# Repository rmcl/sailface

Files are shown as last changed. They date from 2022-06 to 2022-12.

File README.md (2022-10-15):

# SailFace

An autonomous (non-sail powered) boat thing.

# Photos

## Mark II

## Mark I

# Code organization

## Microcontroller (sailface)

Runs on an arduino MEGA. This code manages navigation, communication and power management.

## Control (sailface_control)

Python code for controling sailface remotely.

### Lambda Data Capture (lambda_data_capture)

This module is a lambda function that will receive the messages relayed from the Iridium Short-Burst Data (SBD) network via the RockBLOCK service (https://docs.rockblock.rock7.com/docs/getting-started). 

### Command Lib (sailface_command)

A python library for creating command messages that can be sent to the vessel.

### Notebooks

Various jupyter notebooks for processing KML + sending commands to the vessel.

## Schematics

PCB/Schematic Designs for an Arduino shield which connects the various electronic components. Created using KiCAD

## 3dmodels

3d models for various parts largely for supporting the internals of the vessel.

# Communication

The Arduino communicates sends messages to the Iridium Short-Burst Data services via a RockBLOCK 9603.

SailFace status messages:

### Power

```
P:<batteryVoltage>,batteryCurrentDraw,solarPanelCurrent
P:3.70,500,400
```

### Navigation/Position

```
N:<positionValid>,<latitude>,<longitude>,<speed>,<course>,<gpsFixAge>
```

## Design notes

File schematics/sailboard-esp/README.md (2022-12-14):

Changelog
##################

Version 1.1
---------------------
* Moved towards using a buck converter from Vin to 5V and then a simple linear regulator for 5v to 3.3v

Version 1.2
------------------
* Added dampening capacitor next to servo.

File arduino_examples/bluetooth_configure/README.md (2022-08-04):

# Bluetooth Configure

These sketches can be used to enter AT mode of the HC-05 bluetooth module. The Arduino forwards serial commands enter from a connect computer to the bluetooth module. The serial connection to the module is opened at baud rate 38400 which causes the device to enter AT command mode.

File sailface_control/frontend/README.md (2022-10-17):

# to test in a browser run:

```
python3 -m http.server
```

Then navigate to localhost:8000/examples.html

# Useful links

* https://map.openseamap.org/
* https://wiki.openseamap.org/wiki/h:De:OpenSeaMap_in_Website
* https://mcuoneclipse.com/2014/06/07/combining-gps-data-logger-with-google-earth/
* https://simplekml.readthedocs.io/en/latest/gettingstarted.html#creating-a-point
* https://blog.nicolasmesa.co/posts/2018/09/serve-your-current-directory-with-python-and-http/
* https://wiki.openseamap.org/wiki/h:De:OpenSeaMap_in_Website
* https://mcuoneclipse.com/2014/06/07/combining-gps-data-logger-with-google-earth/
* https://simplekml.readthedocs.io/en/latest/gettingstarted.html#creating-a-point
* https://blog.nicolasmesa.co/posts/2018/09/serve-your-current-directory-with-python-and-http/

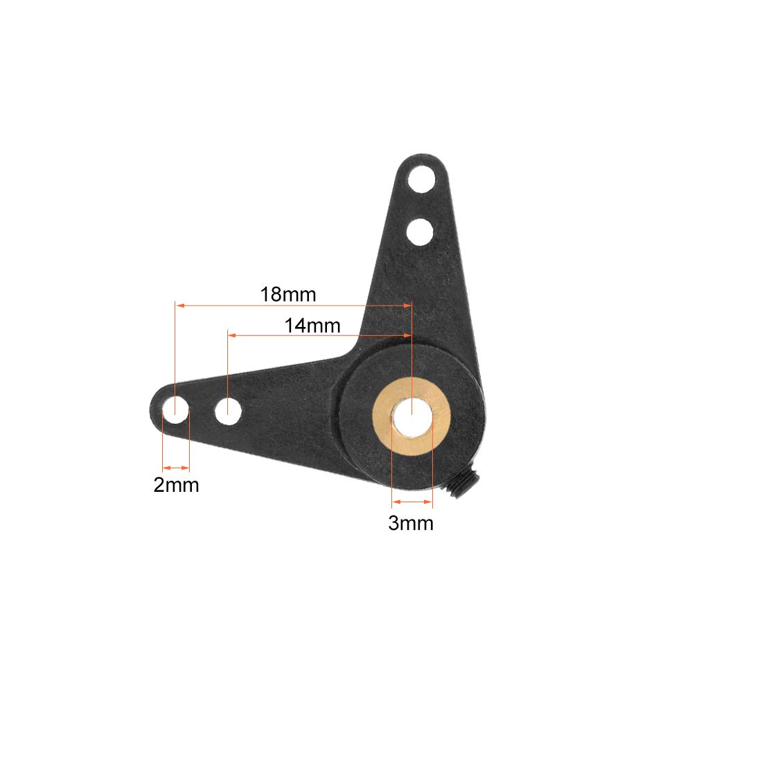
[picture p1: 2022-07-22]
3dmodels/part-photos/rudder_connector.png

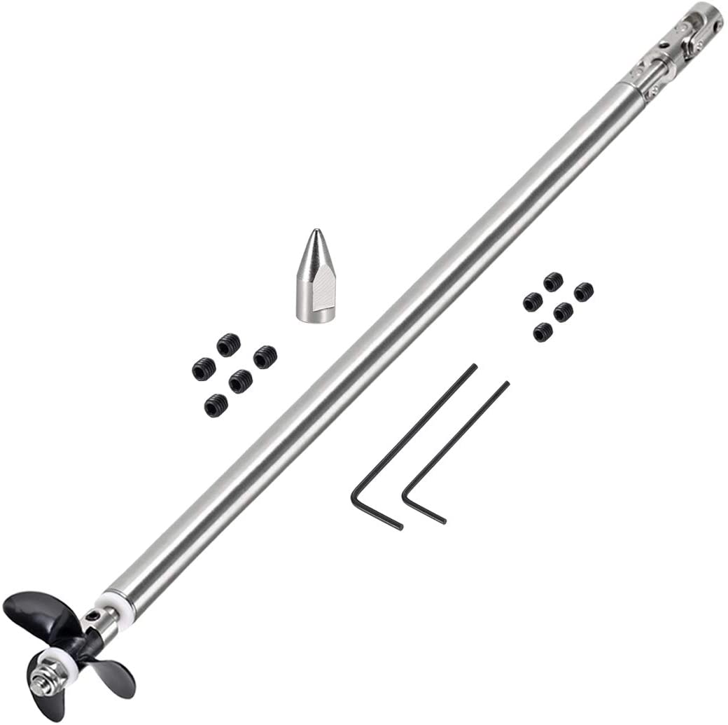
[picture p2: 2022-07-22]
3dmodels/part-photos/prop_with_sleeve.jpeg

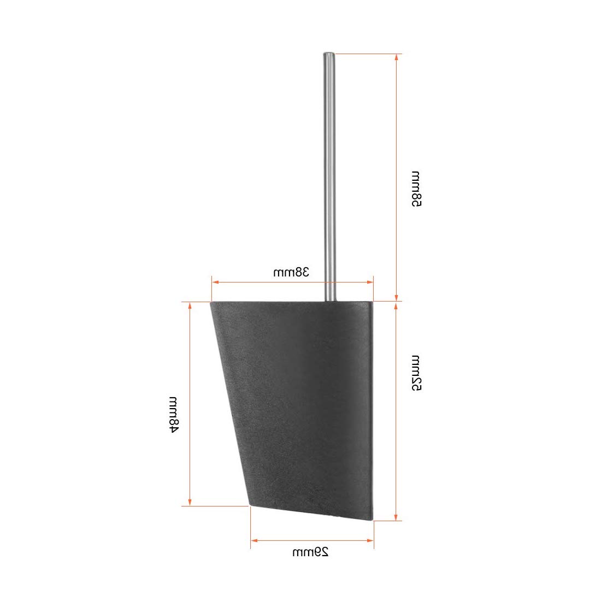
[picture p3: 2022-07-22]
3dmodels/part-photos/rudder.jpg

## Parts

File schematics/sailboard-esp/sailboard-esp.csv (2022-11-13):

Source: | /Users/rmcl/Documents/Arduino/sailface/schematics/sailboard/sailboard.kicad_sch
Date: | Tuesday, September 27, 2022 at 10:22:36 PM
Tool: | Eeschema (6.0.6-0)
Generator: | /Applications/KiCad/KiCad.app/Contents/SharedSupport/plugins/bom_csv_grouped_by_value.py
Component Count: | 29
Individual Components:
Item | Qty | Reference(s) | Value | LibPart | Footprint | Datasheet
 |  | ArduCam1 | ArduCamShield_OV2640 | Russell:ArduCamShield_OV2640 | Connector_PinHeader_2.00mm:PinHeader_1x08_P2.00mm_Vertical
 |  | ATMEGA1 | ATmega2560-16A | Russell:ATmega2560-16A-CustomPins | Package_QFP:TQFP-100_14x14mm_P0.5mm | http://ww1.microchip.com/downloads/en/DeviceDoc/Atmel-2549-8-bit-AVR-Microcontroller-ATmega640-1280-1281-2560-2561_datasheet.pdf
 |  | BATIN1 | BatteryInput | Connector:Conn_01x02_Male | Connector_PinHeader_2.00mm:PinHeader_1x02_P2.00mm_Vertical | ~
 |  | C1 | C | Device:C | Capacitor_SMD:C_0603_1608Metric | ~
 |  | C2 | .1uF | Device:C | Capacitor_SMD:C_0603_1608Metric | ~
 |  | C3 | C | Device:C | Capacitor_SMD:C_0603_1608Metric | ~
 |  | C4 | 10uF | Device:C | Capacitor_SMD:C_0603_1608Metric | ~
 |  | C5 | 100n | Device:C | Capacitor_SMD:C_0603_1608Metric | ~
 |  | C6 | 100nF | Device:C | Capacitor_SMD:C_0603_1608Metric | ~
 |  | C7 | 22pF | Device:C | Capacitor_SMD:C_0603_1608Metric | ~
 |  | C8 | 22pF | Device:C | Capacitor_SMD:C_0603_1608Metric | ~
 |  | C9 | 100nF | Device:C | Capacitor_SMD:C_0603_1608Metric | ~
 |  | C10 | 100nF | Device:C | Capacitor_SMD:C_0603_1608Metric | ~
 |  | C11 | 100nF | Device:C | Capacitor_SMD:C_0603_1608Metric | ~
 |  | COMPASS1 | QMC5883L | Russell:QMC5883L | Connector_PinHeader_2.00mm:PinHeader_1x05_P2.00mm_Vertical | http://wiki.sunfounder.cc/index.php?title=QMC5883L
 |  | D1 | D_Schottky | Device:D_Schottky | Diode_THT:D_5W_P5.08mm_Vertical_AnodeUp | ~
 |  | D2 | LED | Device:LED | LED_SMD:LED_0402_1005Metric | ~
 |  | GPS1 | GPS | Russell:GPS | Connector_PinHeader_1.00mm:PinHeader_1x04_P1.00mm_Vertical
 |  | IRIDIUM1 | IRIDIUM | Russell:IRIDIUM | Connector_PinHeader_2.00mm:PinHeader_1x10_P2.00mm_Vertical | ~
 |  | ISP1 | AVR-ISP-6 | Connector:AVR-ISP-6 | Connector_PinHeader_2.54mm:PinHeader_2x03_P2.54mm_Vertical | ~
 |  | J2 | MainPowerSwitch | Connector:Conn_01x02_Male | Connector_PinHeader_2.00mm:PinHeader_1x02_P2.00mm_Vertical | ~
 |  | MOTOR1 | MOTOR | Connector_Generic:Conn_01x02 | Connector_PinHeader_2.00mm:PinHeader_1x02_P2.00mm_Vertical | ~
 |  | R1 | 1K | Device:R_US | Resistor_SMD:R_0603_1608Metric | ~
 |  | RUDDER1 | RUDDERSERVO | Connector_Generic:Conn_01x03 | Connector_PinHeader_2.00mm:PinHeader_1x03_P2.00mm_Vertical | ~
 |  | SDCARD1 | SD Card | Russell:SD Card | Connector_PinHeader_2.00mm:PinHeader_1x06_P2.00mm_Vertical | https://www.amazon.com/dp/B07BJ2P6X6?psc=1&ref=ppx_yo2ov_dt_b_product_details
 |  | U1 | uA7805 | Regulator_Linear:uA7805 | Package_TO_SOT_THT:TO-220-3_Vertical | http://www.ti.com/lit/ds/symlink/ua78.pdf
 |  | U2 | LM2937xMP | Regulator_Linear:LM2937xMP | Package_TO_SOT_SMD:SOT-223-3_TabPin2 | http://www.ti.com/lit/ds/symlink/lm2937.pdf
 |  | U3 | L293D | Driver_Motor:L293D | Package_DIP:DIP-16_W7.62mm | http://www.ti.com/lit/ds/symlink/l293.pdf
 |  | Y1 | 16MHZ | Device:Crystal | Crystal:Crystal_HC49-4H_Vertical | ~
Collated Components:
Item | Qty | Reference(s) | Value | LibPart | Footprint | Datasheet
1 | 1 | ArduCam1 | ArduCamShield_OV2640 | Russell:ArduCamShield_OV2640 | Connector_PinHeader_2.00mm:PinHeader_1x08_P2.00mm_Vertical
2 | 1 | ATMEGA1 | ATmega2560-16A | Russell:ATmega2560-16A-CustomPins | Package_QFP:TQFP-100_14x14mm_P0.5mm | http://ww1.microchip.com/downloads/en/DeviceDoc/Atmel-2549-8-bit-AVR-Microcontroller-ATmega640-1280-1281-2560-2561_datasheet.pdf
3 | 1 | BATIN1 | BatteryInput | Connector:Conn_01x02_Male | Connector_PinHeader_2.00mm:PinHeader_1x02_P2.00mm_Vertical | ~
4 | 2 | C1, C3 | C | Device:C | Capacitor_SMD:C_0603_1608Metric | ~
5 | 1 | C2 | .1uF | Device:C | Capacitor_SMD:C_0603_1608Metric | ~
6 | 1 | C4 | 10uF | Device:C | Capacitor_SMD:C_0603_1608Metric | ~
7 | 1 | C5 | 100n | Device:C | Capacitor_SMD:C_0603_1608Metric | ~
8 | 4 | C6, C9, C10, C11 | 100nF | Device:C | Capacitor_SMD:C_0603_1608Metric | ~
9 | 2 | C7, C8 | 22pF | Device:C | Capacitor_SMD:C_0603_1608Metric | ~
10 | 1 | COMPASS1 | QMC5883L | Russell:QMC5883L | Connector_PinHeader_2.00mm:PinHeader_1x05_P2.00mm_Vertical | http://wiki.sunfounder.cc/index.php?title=QMC5883L
11 | 1 | D1 | D_Schottky | Device:D_Schottky | Diode_THT:D_5W_P5.08mm_Vertical_AnodeUp | ~
12 | 1 | D2 | LED | Device:LED | LED_SMD:LED_0402_1005Metric | ~
13 | 1 | GPS1 | GPS | Russell:GPS | Connector_PinHeader_1.00mm:PinHeader_1x04_P1.00mm_Vertical
14 | 1 | IRIDIUM1 | IRIDIUM | Russell:IRIDIUM | Connector_PinHeader_2.00mm:PinHeader_1x10_P2.00mm_Vertical | ~
15 | 1 | ISP1 | AVR-ISP-6 | Connector:AVR-ISP-6 | Connector_PinHeader_2.54mm:PinHeader_2x03_P2.54mm_Vertical | ~
16 | 1 | J2 | MainPowerSwitch | Connector:Conn_01x02_Male | Connector_PinHeader_2.00mm:PinHeader_1x02_P2.00mm_Vertical | ~
17 | 1 | MOTOR1 | MOTOR | Connector_Generic:Conn_01x02 | Connector_PinHeader_2.00mm:PinHeader_1x02_P2.00mm_Vertical | ~
18 | 1 | R1 | 1K | Device:R_US | Resistor_SMD:R_0603_1608Metric | ~
19 | 1 | RUDDER1 | RUDDERSERVO | Connector_Generic:Conn_01x03 | Connector_PinHeader_2.00mm:PinHeader_1x03_P2.00mm_Vertical | ~
20 | 1 | SDCARD1 | SD Card | Russell:SD Card | Connector_PinHeader_2.00mm:PinHeader_1x06_P2.00mm_Vertical | https://www.amazon.com/dp/B07BJ2P6X6?psc=1&ref=ppx_yo2ov_dt_b_product_details
21 | 1 | U1 | uA7805 | Regulator_Linear:uA7805 | Package_TO_SOT_THT:TO-220-3_Vertical | http://www.ti.com/lit/ds/symlink/ua78.pdf
22 | 1 | U2 | LM2937xMP | Regulator_Linear:LM2937xMP | Package_TO_SOT_SMD:SOT-223-3_TabPin2 | http://www.ti.com/lit/ds/symlink/lm2937.pdf
23 | 1 | U3 | L293D | Driver_Motor:L293D | Package_DIP:DIP-16_W7.62mm | http://www.ti.com/lit/ds/symlink/l293.pdf
24 | 1 | Y1 | 16MHZ | Device:Crystal | Crystal:Crystal_HC49-4H_Vertical | ~

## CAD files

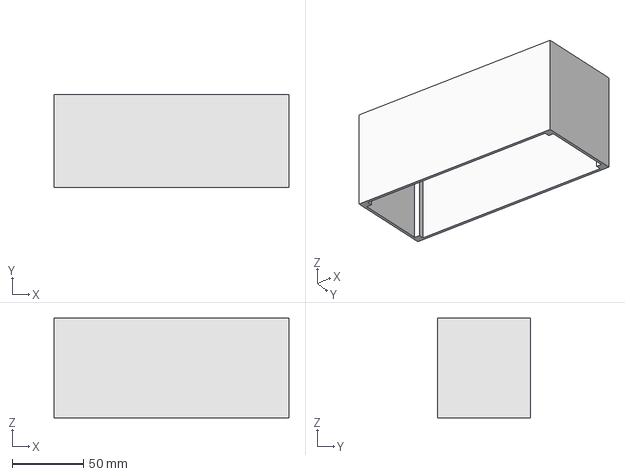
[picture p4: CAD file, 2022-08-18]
ElectronicAssembly_v2.1.FCStd
165.0 x 65.0 x 70.0 mm

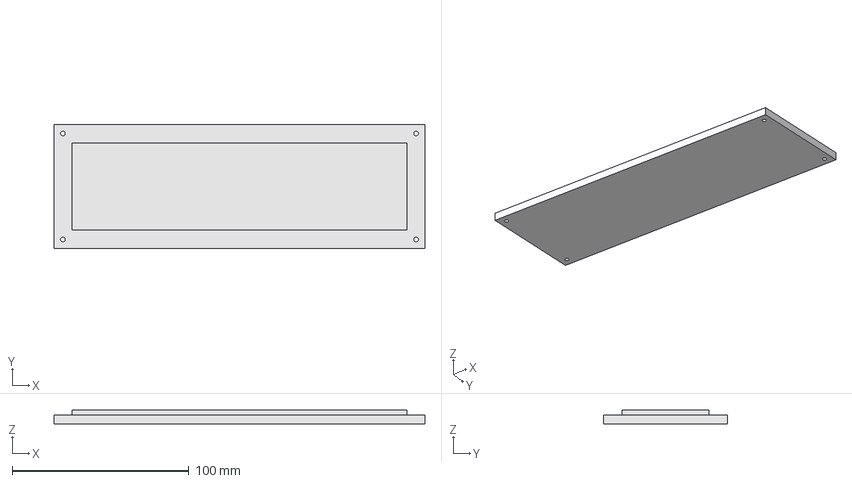
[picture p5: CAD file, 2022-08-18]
3dmodels/ElectronicAssembly_v3.FCStd
210.0 x 70.0 x 8.00 mm

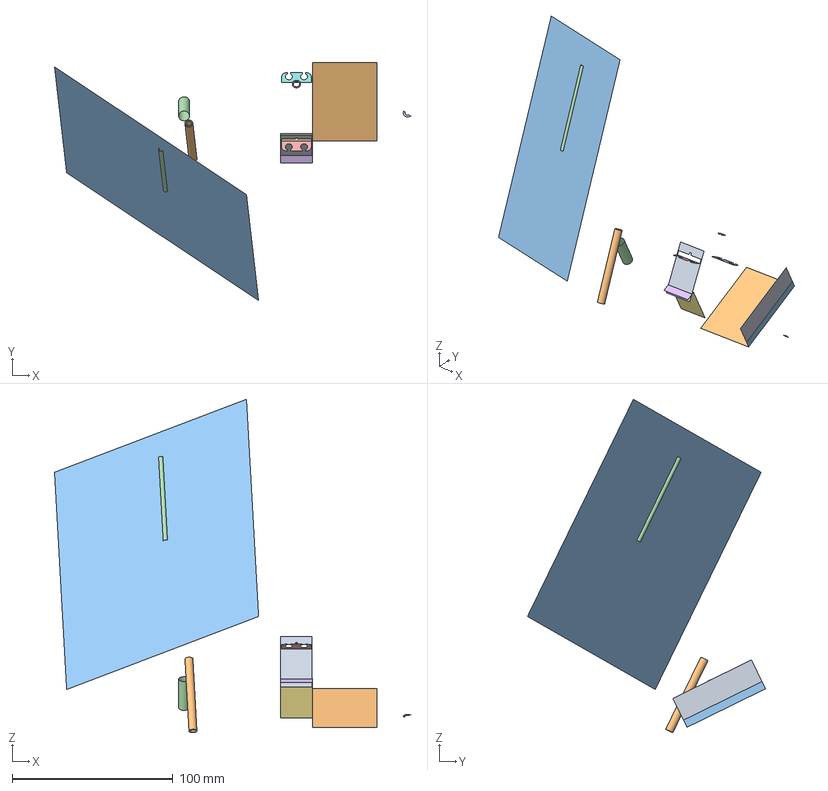
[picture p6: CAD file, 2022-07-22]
3dmodels/sailface_steerage_assembly_v1.FCStd
221.7 x 148.3 x 207.7 mm
Element
Element001
Element002
_Element
_Element002
_Element003
_Element004
_Element005
_Element008
_Element022
YZ_Plane@PartRudderWithPost
_Element025
_Element026
_Element027
_Element028

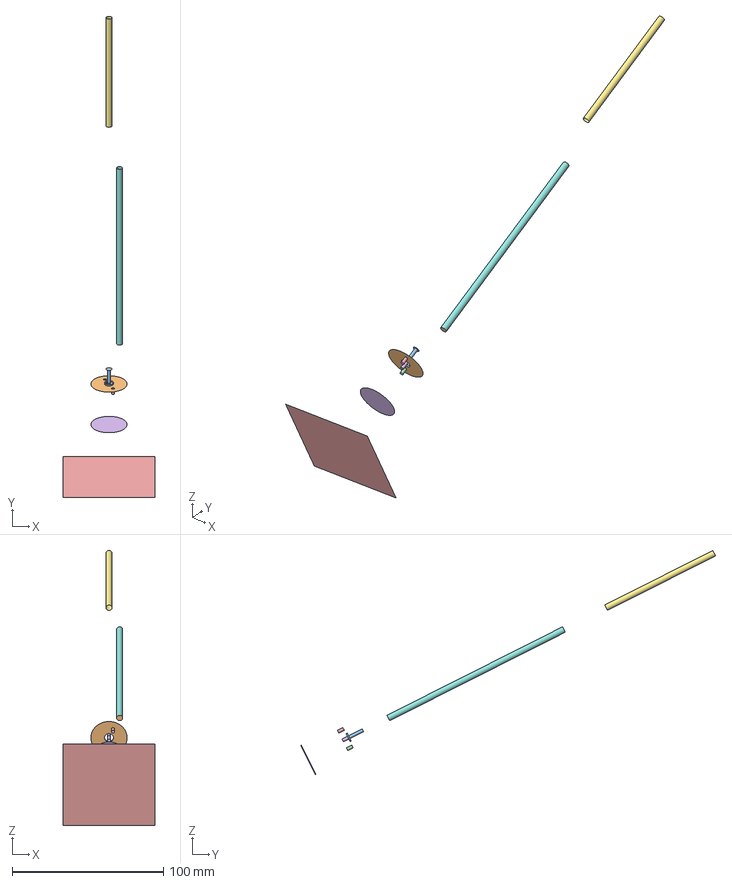
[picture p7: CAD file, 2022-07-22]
3dmodels/sailface_prop_motor_assembly.FCStd
60.5 x 317.8 x 181.6 mm
Element
Element001
Element002
Element003
Element004
_Element
_Element043
_Element044
_Element045
_Element046
_Element047
_Element048
_Element049
_Element050

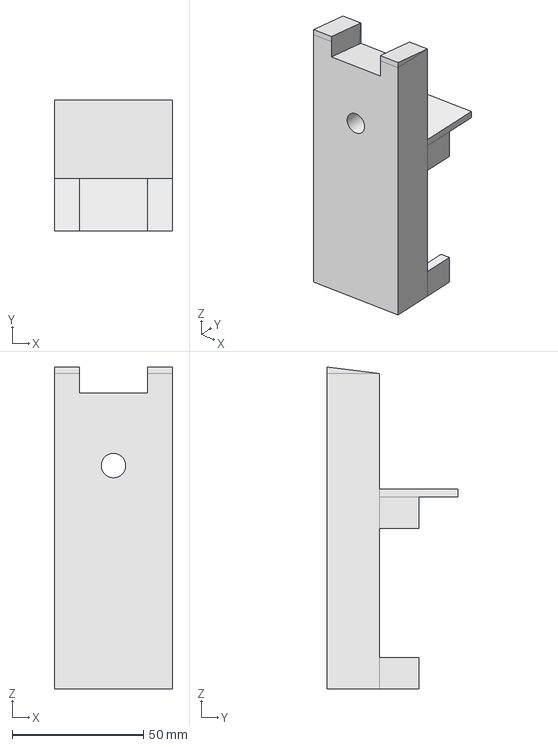
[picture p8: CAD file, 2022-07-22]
3dmodels/sailface_vertical_assembly_v3.FCStd
45.0 x 50.0 x 122.5 mm

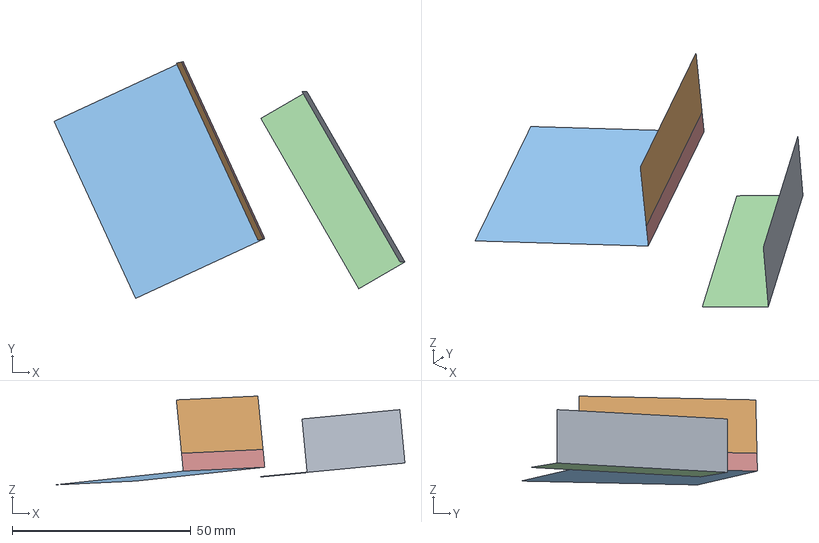
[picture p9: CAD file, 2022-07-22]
3dmodels/sailface_assembly_v2.FCStd
98.1 x 66.2 x 24.9 mm
_Element
_Element001
_Element002
_Element003
_Element004

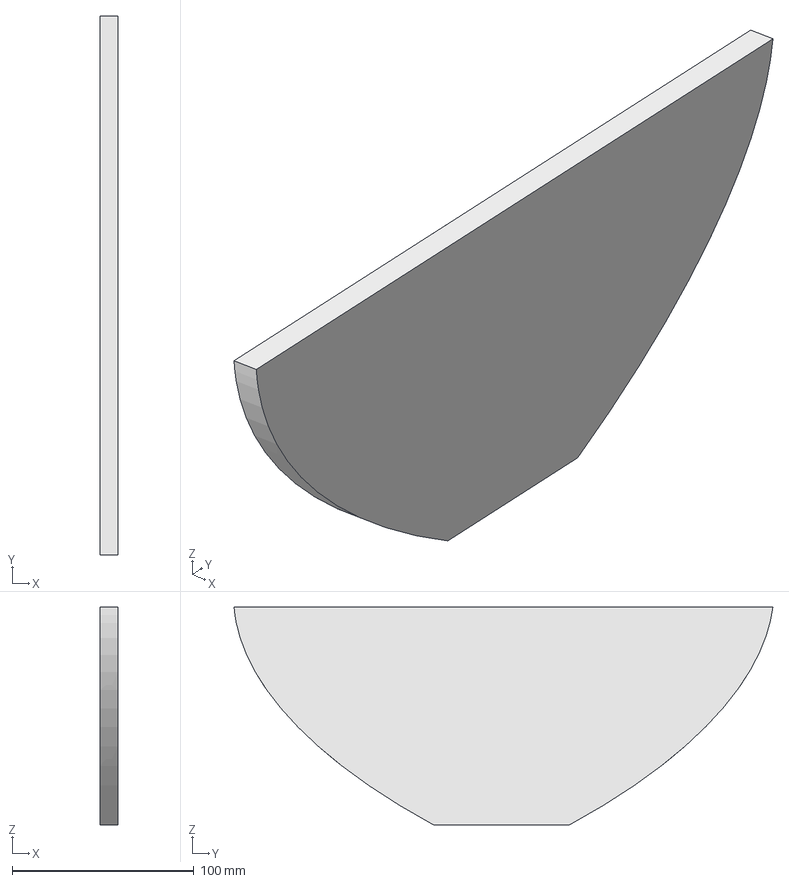
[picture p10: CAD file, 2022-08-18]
3dmodels/hull-experiments/hull_v3.FCStd
10.0 x 296.7 x 120.0 mm

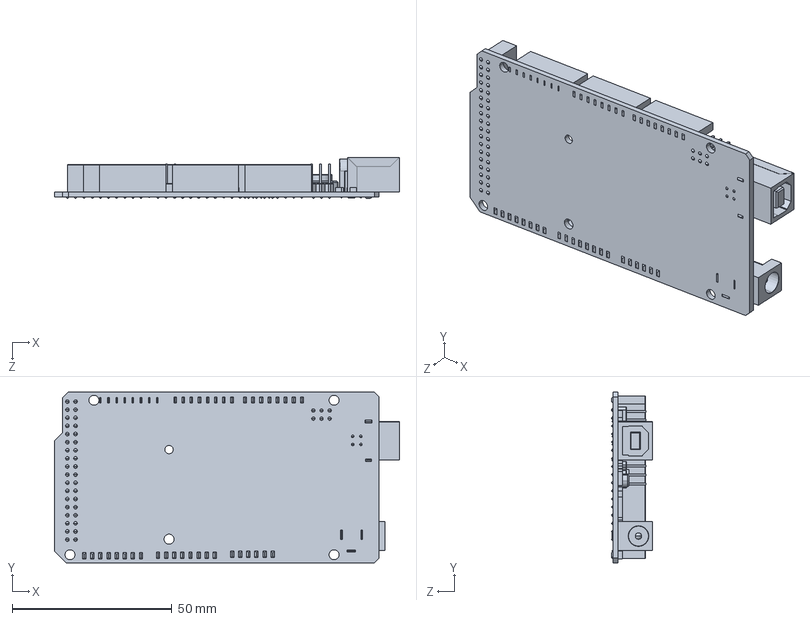
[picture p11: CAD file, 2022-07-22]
3dmodels/part-photos/ArduinoMega_STEP_AP203.STEP
107.9 x 53.4 x 13.0 mm

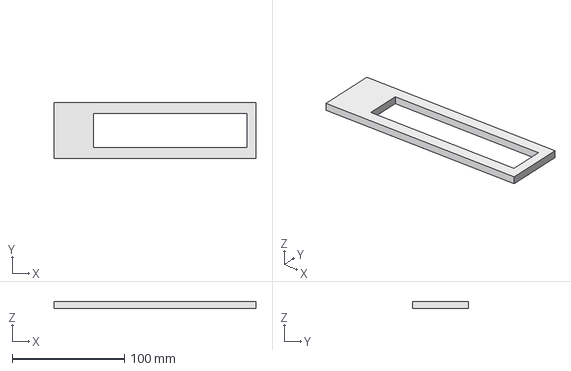
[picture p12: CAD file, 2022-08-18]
3dmodels/MiddleConnector_v1.FCStd
180.0 x 50.0 x 6.00 mm

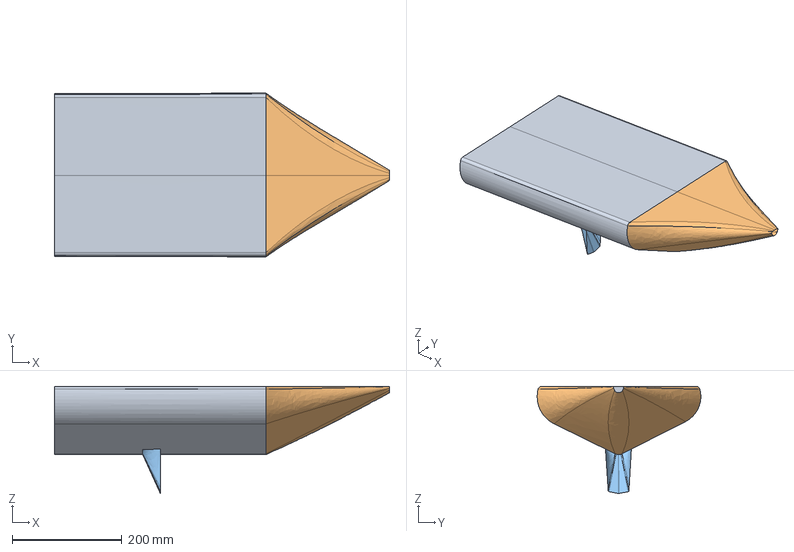
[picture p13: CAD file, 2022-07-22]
3dmodels/hull-experiments/hulltest6.FCStd
610.0 x 298.0 x 195.0 mm

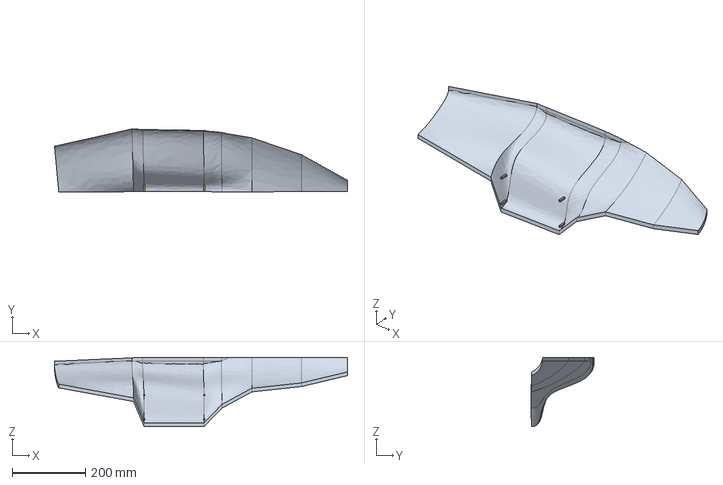
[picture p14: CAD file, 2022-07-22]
3dmodels/hull-experiments/hulltest9_BACKUP.FCStd
801.2 x 173.3 x 190.0 mm
ExtrudeBatteryHolder

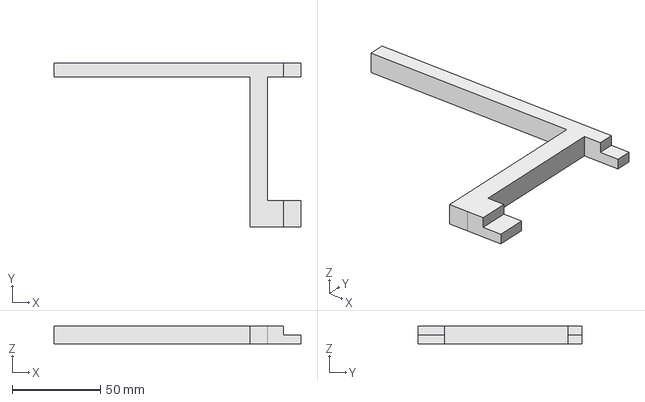
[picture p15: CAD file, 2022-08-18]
3dmodels/SolarPanelSupports_v2.FCStd
140.0 x 93.0 x 10.0 mm

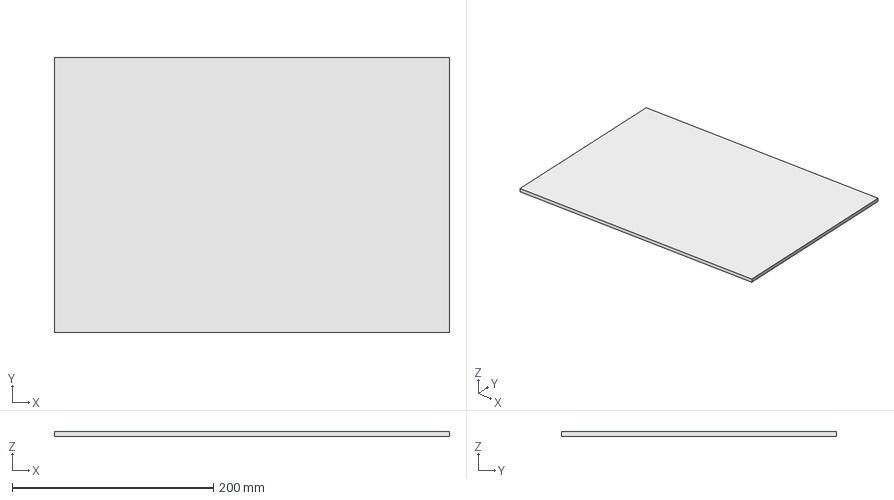
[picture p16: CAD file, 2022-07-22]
3dmodels/sailface.FCStd
393.0 x 274.0 x 5.00 mm

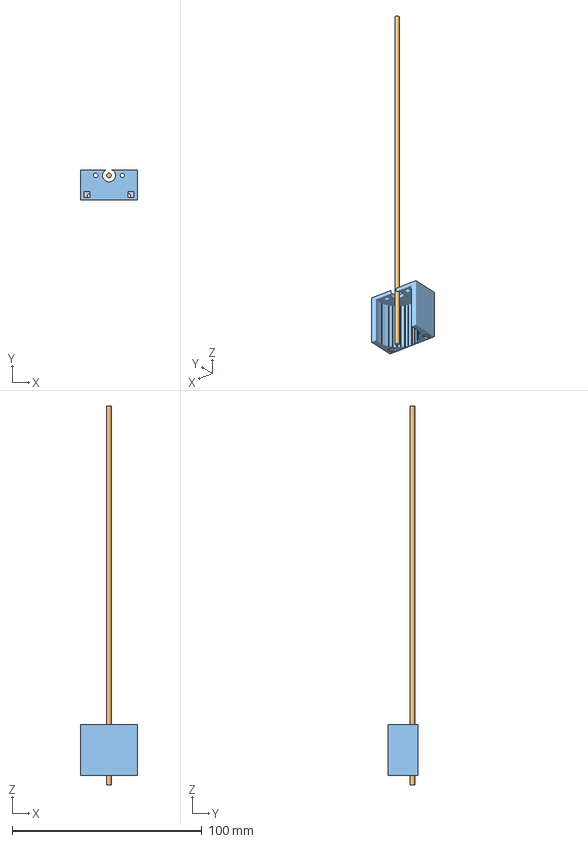
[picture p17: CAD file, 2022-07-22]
3dmodels/motor.FCStd
30.0 x 16.0 x 200.0 mm
MotorHolderBody
MotorHolder (Meshed)

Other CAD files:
3dmodels/assembly4test.FCStd
3dmodels/hull-experiments/hulltest2.FCStd
3dmodels/hull-experiments/hulltest4.FCStd
3dmodels/hull-experiments/hulltest9.FCStd
3dmodels/Battery_VoltaicV70.FCStd
3dmodels/ElectronicAssembly.FCStd
3dmodels/ElectronicAssembly_v2.FCStd
3dmodels/GPSAntennaHolder_v1.FCStd
3dmodels/MotorAndHolder_v1.FCStd
3dmodels/MotorHolderConnect_v1.FCStd
3dmodels/Prop_uxcell_prop_shaft.FCStd
3dmodels/ServoHolder_v2.FCStd
3dmodels/ServoHolder_v3.FCStd
3dmodels/ServoSunFinderSF3218MG.FCStd
3dmodels/ServoSunFinderSF3218MG_v2.FCStd
3dmodels/SolarPanelSupports_v1.FCStd
3dmodels/hull-experiments/hull_v1.FCStd
3dmodels/hull-experiments/hull_v2.FCStd
3dmodels/hull-experiments/hullexperiment-1.FCStd
3dmodels/hull-experiments/hulltest3.FCStd
3dmodels/hull-experiments/hulltest5.FCStd
3dmodels/hull-experiments/hulltest7.FCStd
3dmodels/hull-experiments/hulltest8.FCStd
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

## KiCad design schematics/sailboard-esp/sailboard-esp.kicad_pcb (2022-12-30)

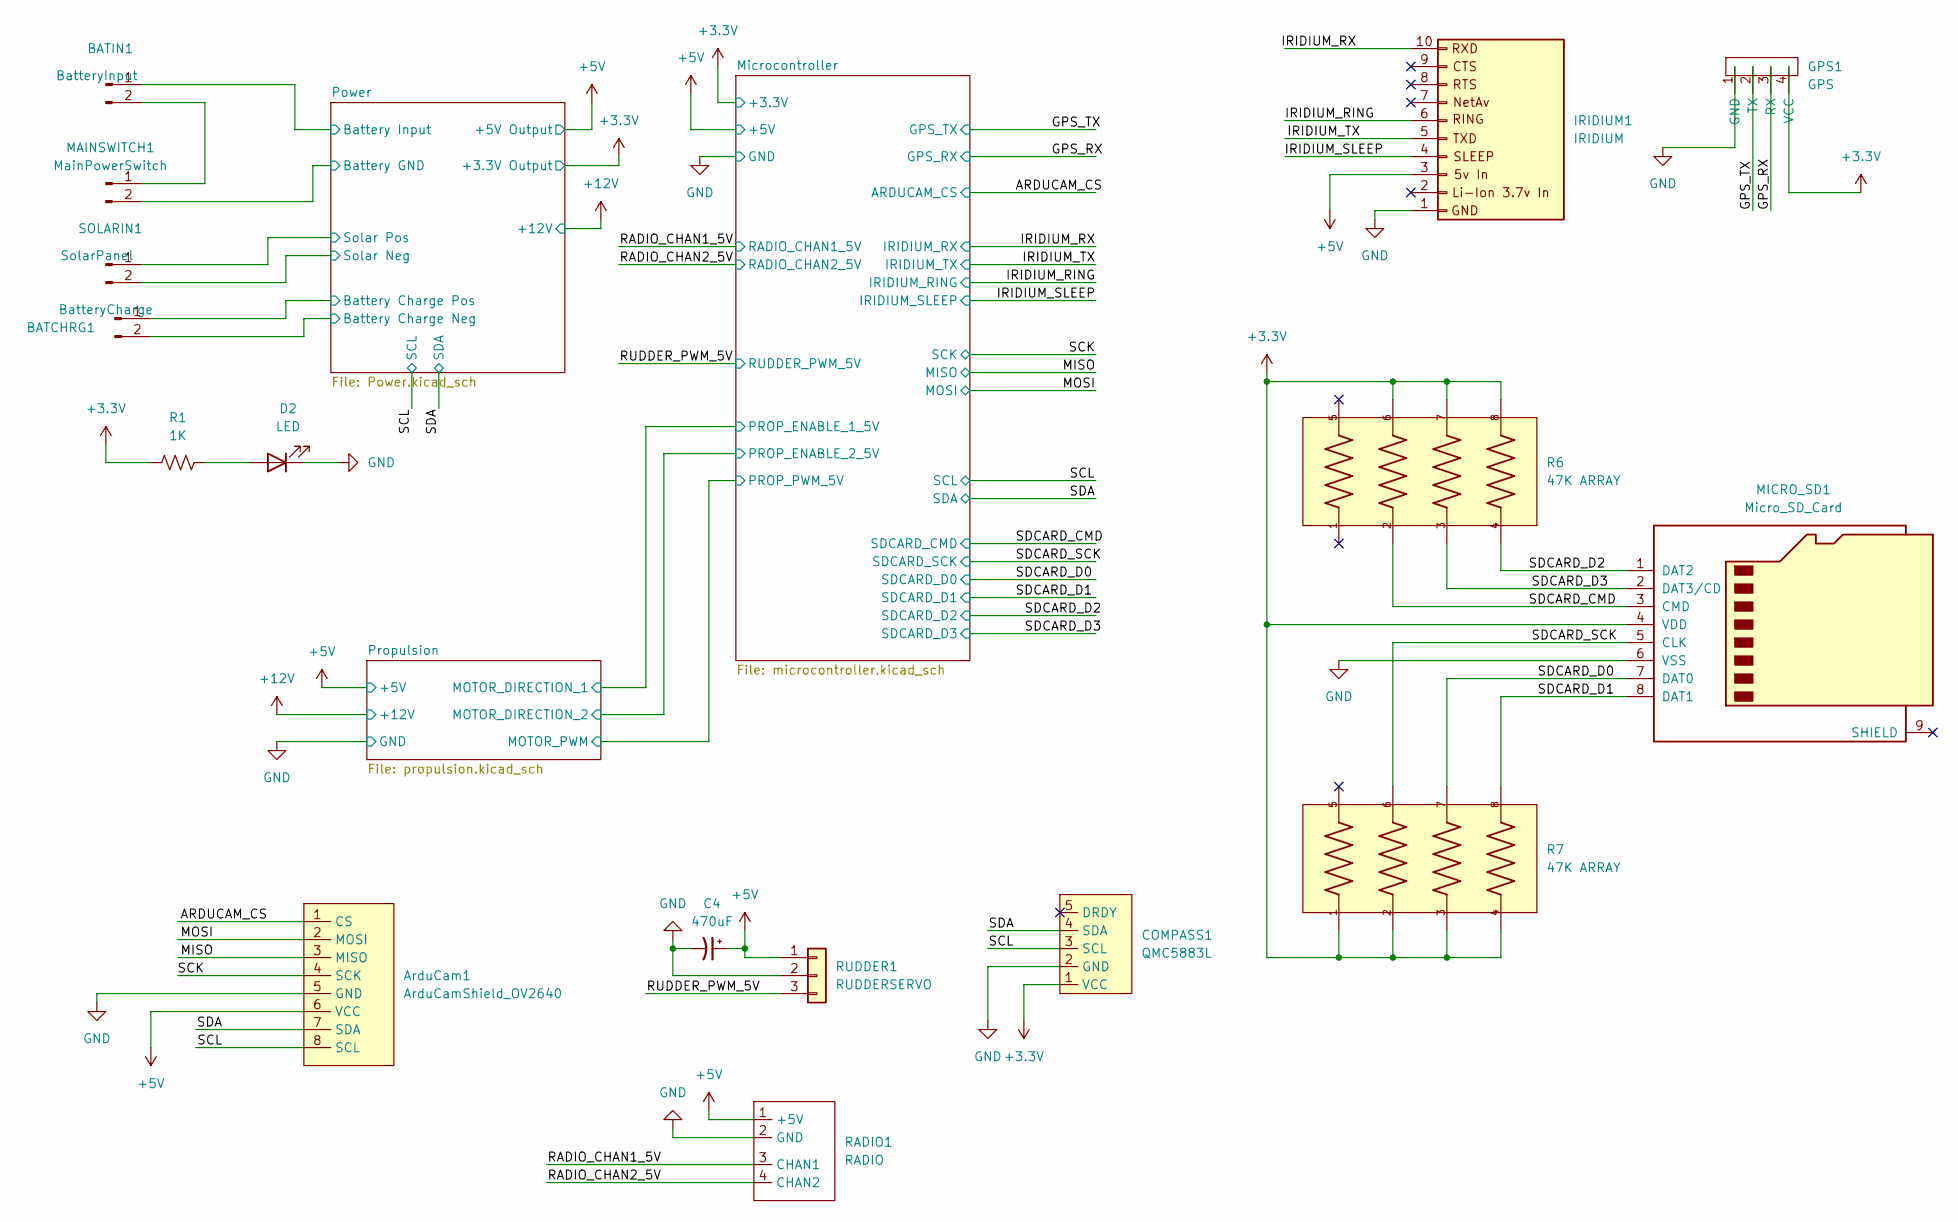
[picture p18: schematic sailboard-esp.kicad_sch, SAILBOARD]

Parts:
ArduCam1: ArduCamShield_OV2640; PinHeader_1x08_P2.54mm_Vertical
BATCHRG1: BatteryCharge; JST_XH_B2B-XH-A_1x02_P2.50mm_Vertical
BATIN1: BatteryInput; JST_XH_B2B-XH-A_1x02_P2.50mm_Vertical
C4: 470uF; CP_Radial_D8.0mm_P3.50mm
COMPASS1: QMC5883L; PinHeader_1x05_P2.54mm_Vertical
D2: LED; LED_0603_1608Metric
GPS1: GPS; PinHeader_1x04_P2.54mm_Vertical
IRIDIUM1: IRIDIUM; Molex_PicoBlade_53047-1010_1x10_P1.25mm_Vertical
MAINSWITCH1: MainPowerSwitch; JST_XH_B2B-XH-A_1x02_P2.50mm_Vertical
MICRO_SD1: Micro_SD_Card; microSD_HC_Molex_104031-0811
R1: 1K; R_0603_1608Metric
R6, R7: 47K ARRAY; RESCAXE80P320X160X70-8N; PARTREV 0
RADIO1: RADIO; PinHeader_1x04_P2.54mm_Vertical
RUDDER1: RUDDERSERVO; JST_XH_B3B-XH-A_1x03_P2.50mm_Vertical
SOLARIN1: SolarPanel; JST_XH_B2B-XH-A_1x02_P2.50mm_Vertical

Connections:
+3.3V: COMPASS1.1 (VCC), GPS1.4 (VCC), MICRO_SD1.4 (VDD), R1.1, R6.6, R6.7, R6.8, R7.1, R7.2, R7.3, R7.4; also elsewhere on the board
+5V: ArduCam1.6 (VCC), C4.1, IRIDIUM1.3 (5V), RADIO1.1 (+5V), RUDDER1.1; also elsewhere on the board
/ARDUCAM_CS: ArduCam1.1 (CS); also elsewhere on the board
/GPS_RX: GPS1.3 (RX)
/GPS_TX: GPS1.2 (TX); also elsewhere on the board
/IRIDIUM_RING: IRIDIUM1.6 (RING); also elsewhere on the board
/IRIDIUM_RX: IRIDIUM1.10 (RXD); also elsewhere on the board
/IRIDIUM_SLEEP: IRIDIUM1.4 (SLEEP); also elsewhere on the board
/IRIDIUM_TX: IRIDIUM1.5 (TXD); also elsewhere on the board
/MISO: ArduCam1.3 (MISO); also elsewhere on the board
/MOSI: ArduCam1.2 (MOSI); also elsewhere on the board
/Power/Battery Charge Neg: BATCHRG1.2, SOLARIN1.2
/Power/Battery Charge Pos: BATCHRG1.1; also elsewhere on the board
/Power/Battery Input: BATIN1.1; also elsewhere on the board
/Power/Solar Pos: SOLARIN1.1; also elsewhere on the board
/RADIO_CHAN1_5V: RADIO1.3 (CHAN1); also elsewhere on the board
/RADIO_CHAN2_5V: RADIO1.4 (CHAN2); also elsewhere on the board
/RUDDER_PWM_5V: RUDDER1.3; also elsewhere on the board
/SCK: ArduCam1.4 (SCK); also elsewhere on the board
/SCL: ArduCam1.8 (SCL), COMPASS1.3 (SCL); also elsewhere on the board
/SDA: ArduCam1.7 (SDA), COMPASS1.4 (SDA); also elsewhere on the board
/SDCARD_CMD: MICRO_SD1.3 (CMD), R6.2; also elsewhere on the board
/SDCARD_D0: MICRO_SD1.7 (DAT0), R7.7; also elsewhere on the board
/SDCARD_D1: MICRO_SD1.8 (DAT1), R7.8; also elsewhere on the board
/SDCARD_D2: MICRO_SD1.1 (DAT2), R6.4; also elsewhere on the board
/SDCARD_D3: MICRO_SD1.2 (DAT3/CD), R6.3; also elsewhere on the board
/SDCARD_SCK: MICRO_SD1.5 (CLK), R7.6; also elsewhere on the board
GND: ArduCam1.5 (GND), C4.2, COMPASS1.2 (GND), D2.1 (K), GPS1.1 (GND), IRIDIUM1.1 (GND), MAINSWITCH1.2, MICRO_SD1.6 (VSS), RADIO1.2 (GND), RUDDER1.2; also elsewhere on the board
unnamed: BATIN1.2, MAINSWITCH1.1
unnamed: D2.2 (A), R1.2

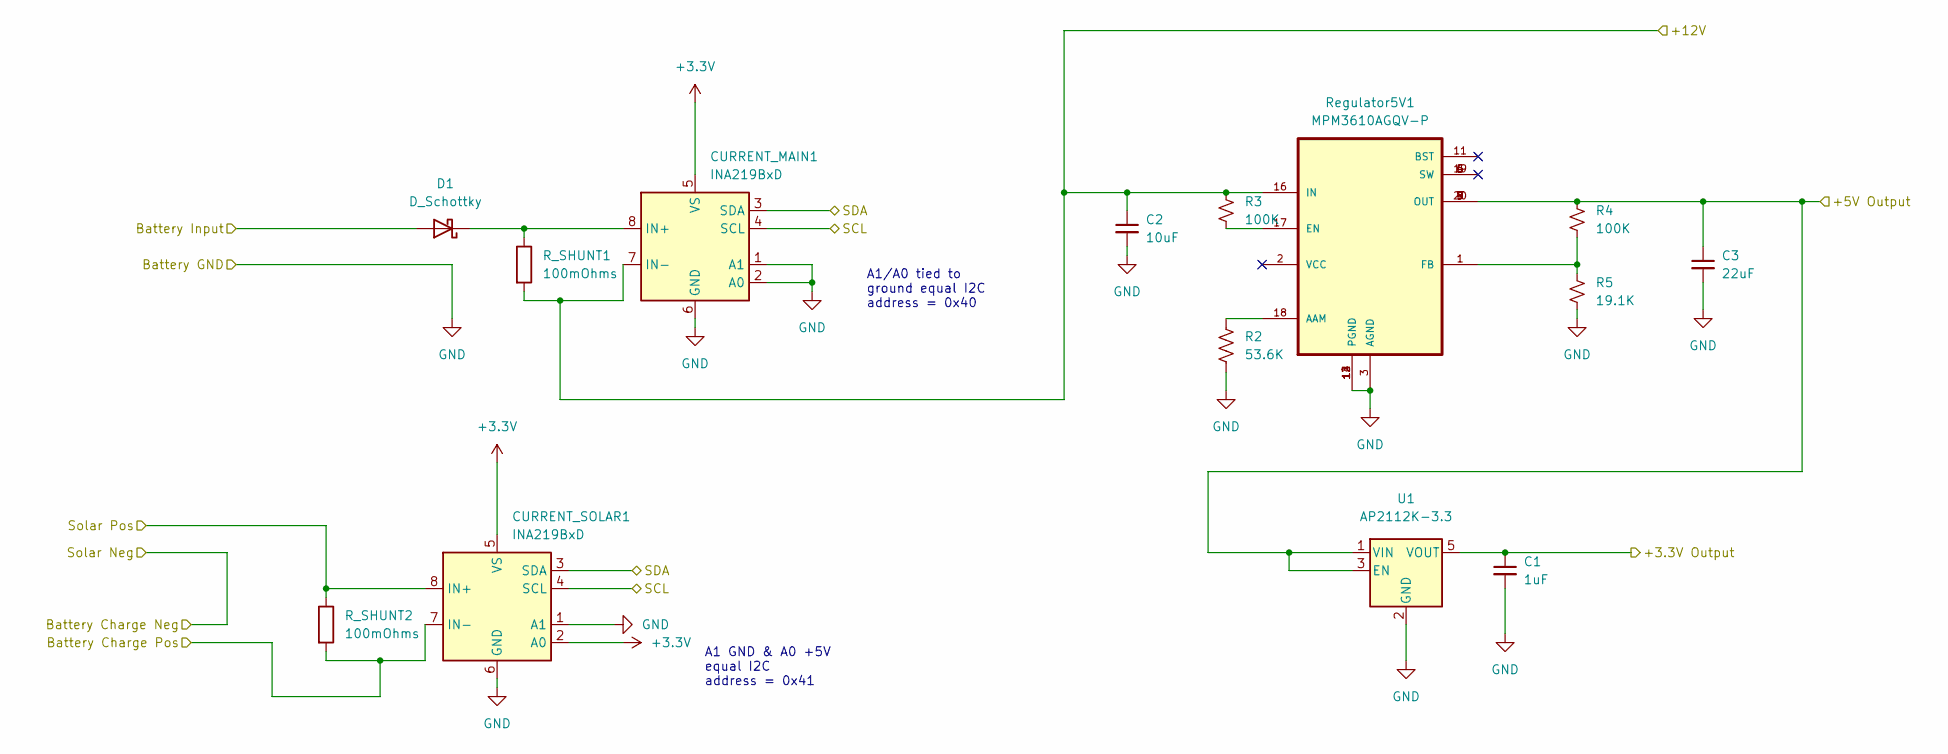
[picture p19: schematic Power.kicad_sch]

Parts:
C1: 1uF; C_0603_1608Metric_Pad1.08x0.95mm_HandSolder
C2: 10uF; C_0603_1608Metric_Pad1.08x0.95mm_HandSolder
C3: 22uF; C_0603_1608Metric_Pad1.08x0.95mm_HandSolder
CURRENT_MAIN1: INA219BxD; SOIC-8_3.9x4.9mm_P1.27mm
CURRENT_SOLAR1: INA219BxD; SOIC-8_3.9x4.9mm_P1.27mm
D1: D_Schottky; D_5W_P5.08mm_Vertical_AnodeUp
R2: 53.6K; R_0603_1608Metric
R3, R4: 100K; R_0603_1608Metric
R5: 19.1K; R_0603_1608Metric
R_SHUNT1, R_SHUNT2: 100mOhms; R_2512_6332Metric
Regulator5V1: MPM3610AGQV-P; MPM3620AGQV-P; PARTREV 1.0
U1: AP2112K-3.3; SOT-23-5

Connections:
+3.3V: C1.1, CURRENT_MAIN1.5 (VS), CURRENT_SOLAR1.2 (A0), CURRENT_SOLAR1.5 (VS), U1.5 (VOUT); also elsewhere on the board
+5V: C3.1, R4.1, Regulator5V1.7 (OUT), Regulator5V1.8 (OUT), Regulator5V1.9 (OUT), Regulator5V1.20 (OUT), U1.1 (VIN), U1.3 (EN); also elsewhere on the board
+12V: C2.1, CURRENT_MAIN1.7 (IN-), R3.1, R_SHUNT1.2, Regulator5V1.16 (IN); also elsewhere on the board
/Power/Battery Charge Pos: CURRENT_SOLAR1.7 (IN-), R_SHUNT2.2; also elsewhere on the board
/Power/Battery Input: D1.2 (A); also elsewhere on the board
/Power/Solar Pos: CURRENT_SOLAR1.8 (IN+), R_SHUNT2.1; also elsewhere on the board
/SCL: CURRENT_MAIN1.4 (SCL), CURRENT_SOLAR1.4 (SCL); also elsewhere on the board
/SDA: CURRENT_MAIN1.3 (SDA), CURRENT_SOLAR1.3 (SDA); also elsewhere on the board
GND: C1.2, C2.2, C3.2, CURRENT_MAIN1.1 (A1), CURRENT_MAIN1.2 (A0), CURRENT_MAIN1.6 (GND), CURRENT_SOLAR1.1 (A1), CURRENT_SOLAR1.6 (GND), R2.2, R5.2, Regulator5V1.3 (AGND), Regulator5V1.12 (PGND), Regulator5V1.13 (PGND), Regulator5V1.14 (PGND), U1.2 (GND); also elsewhere on the board
unnamed: CURRENT_MAIN1.8 (IN+), D1.1 (K), R_SHUNT1.1
unnamed: R2.1, Regulator5V1.18 (AAM)
unnamed: R3.2, Regulator5V1.17 (EN)
unnamed: R4.2, R5.1, Regulator5V1.1 (FB)

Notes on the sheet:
A1 GND & A0 +5V equal I2C address = 0x41
A1/A0 tied to ground equal I2C address = 0x40

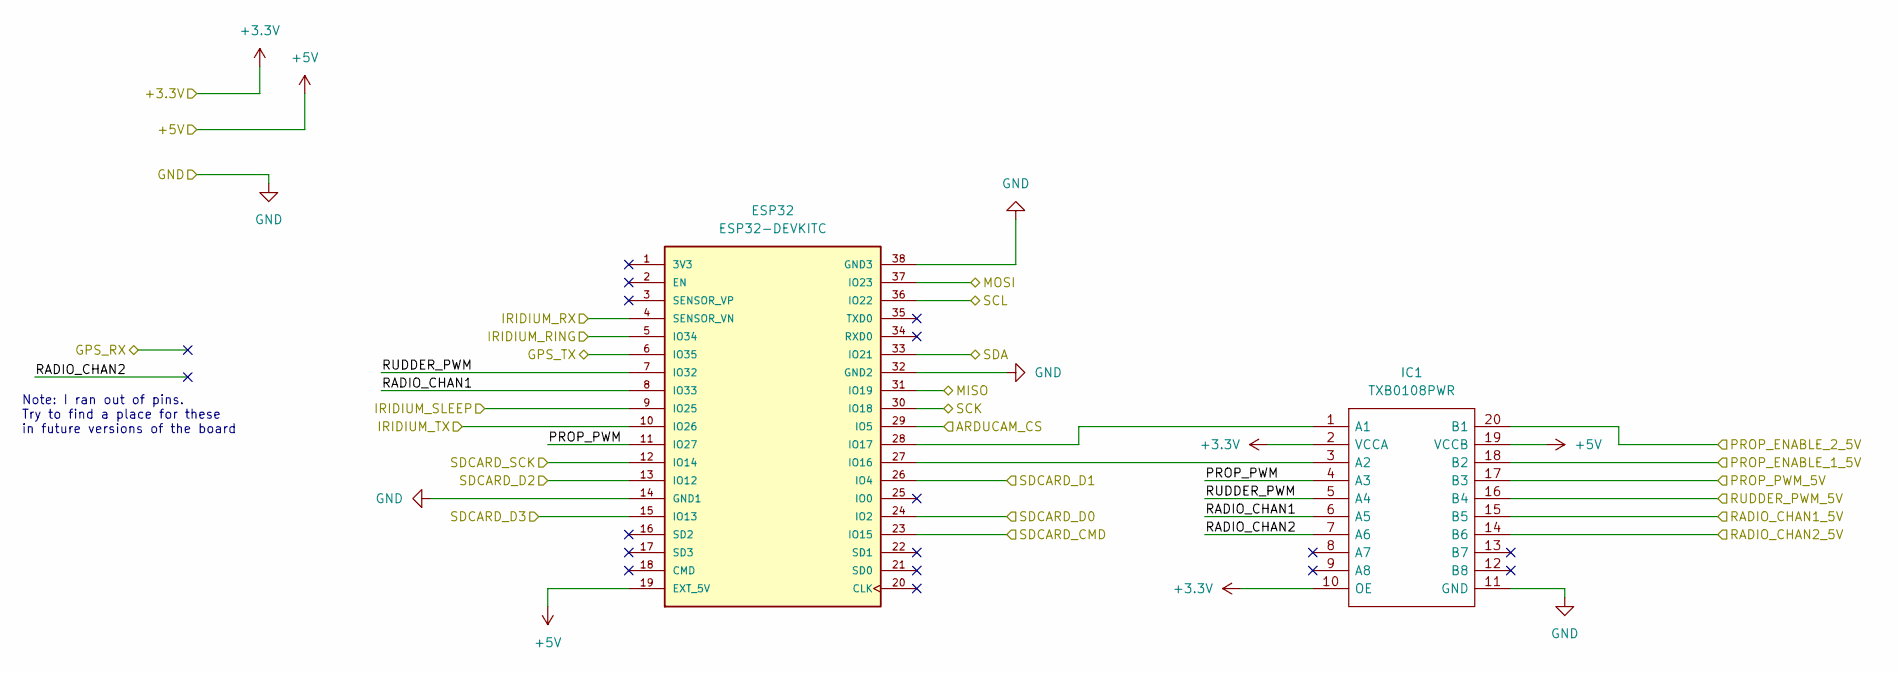
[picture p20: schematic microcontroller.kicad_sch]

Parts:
ESP32: ESP32-DEVKITC; MODULE_ESP32-DEVKITC-RESIZED; PARTREV N/A
IC1: TXB0108PWR; SOP65P640X120-20N; Manufacturer_Part_Number TXB0108PWR; Mouser Part Number 595-TXB0108PWR

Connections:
+3.3V: IC1.2 (VCCA), IC1.10 (OE); also elsewhere on the board
+5V: ESP32.19 (EXT_5V), IC1.19 (VCCB); also elsewhere on the board
/ARDUCAM_CS: ESP32.29 (IO5); also elsewhere on the board
/GPS_TX: ESP32.6 (IO35); also elsewhere on the board
/IRIDIUM_RING: ESP32.5 (IO34); also elsewhere on the board
/IRIDIUM_RX: ESP32.4 (SENSOR_VN); also elsewhere on the board
/IRIDIUM_SLEEP: ESP32.9 (IO25); also elsewhere on the board
/IRIDIUM_TX: ESP32.10 (IO26); also elsewhere on the board
/MISO: ESP32.31 (IO19); also elsewhere on the board
/MOSI: ESP32.37 (IO23); also elsewhere on the board
/Microcontroller/PROP_ENABLE_1_5V: IC1.18 (B2); also elsewhere on the board
/Microcontroller/PROP_ENABLE_2_5V: IC1.20 (B1); also elsewhere on the board
/Microcontroller/PROP_PWM: ESP32.11 (IO27), IC1.4 (A3)
/Microcontroller/PROP_PWM_5V: IC1.17 (B3); also elsewhere on the board
/Microcontroller/RADIO_CHAN1: ESP32.8 (IO33), IC1.6 (A5)
/Microcontroller/RADIO_CHAN2: IC1.7 (A6)
/Microcontroller/RUDDER_PWM: ESP32.7 (IO32), IC1.5 (A4)
/RADIO_CHAN1_5V: IC1.15 (B5); also elsewhere on the board
/RADIO_CHAN2_5V: IC1.14 (B6); also elsewhere on the board
/RUDDER_PWM_5V: IC1.16 (B4); also elsewhere on the board
/SCK: ESP32.30 (IO18); also elsewhere on the board
/SCL: ESP32.36 (IO22); also elsewhere on the board
/SDA: ESP32.33 (IO21); also elsewhere on the board
/SDCARD_CMD: ESP32.23 (IO15); also elsewhere on the board
/SDCARD_D0: ESP32.24 (IO2); also elsewhere on the board
/SDCARD_D1: ESP32.26 (IO4); also elsewhere on the board
/SDCARD_D2: ESP32.13 (IO12); also elsewhere on the board
/SDCARD_D3: ESP32.15 (IO13); also elsewhere on the board
/SDCARD_SCK: ESP32.12 (IO14); also elsewhere on the board
GND: ESP32.14 (GND1), ESP32.32 (GND2), ESP32.38 (GND3), IC1.11 (GND); also elsewhere on the board
unnamed: ESP32.27 (IO16), IC1.3 (A2)
unnamed: ESP32.28 (IO17), IC1.1 (A1)

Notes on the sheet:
Note: I ran out of pins. Try to find a place for these in future versions of the board

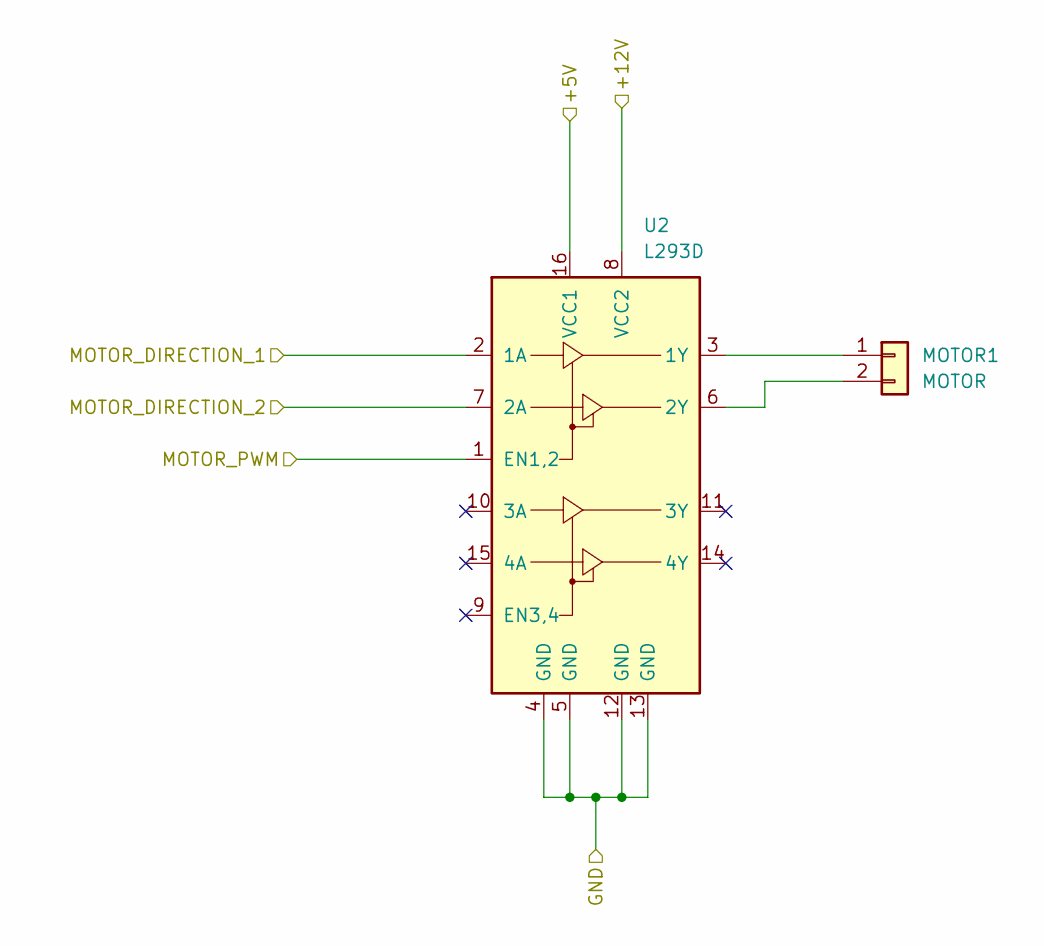
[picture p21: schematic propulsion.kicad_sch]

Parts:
MOTOR1: MOTOR; JST_XH_B2B-XH-A_1x02_P2.50mm_Vertical
U2: L293D; DIP-16_W7.62mm

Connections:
+5V: U2.16 (VCC1); also elsewhere on the board
+12V: U2.8 (VCC2); also elsewhere on the board
/Microcontroller/PROP_ENABLE_1_5V: U2.2 (1A); also elsewhere on the board
/Microcontroller/PROP_ENABLE_2_5V: U2.7 (2A); also elsewhere on the board
/Microcontroller/PROP_PWM_5V: U2.1 (EN1,2); also elsewhere on the board
GND: U2.4 (GND), U2.5 (GND), U2.12 (GND), U2.13 (GND); also elsewhere on the board
unnamed: MOTOR1.1, U2.3 (1Y)
unnamed: MOTOR1.2, U2.6 (2Y)

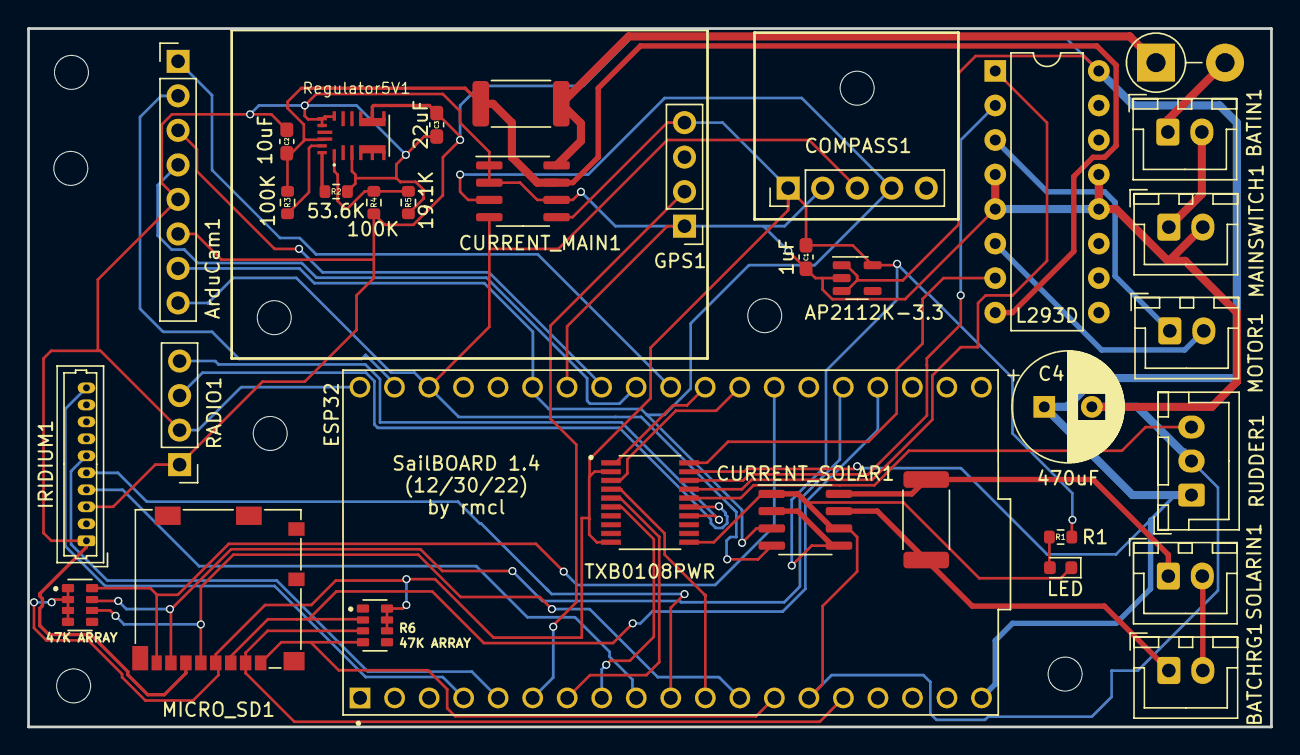
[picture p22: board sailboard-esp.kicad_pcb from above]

Board: 2 copper layers, 91.4 x 51.4 mm, 38 parts (0 on the bottom side), 44 nets.

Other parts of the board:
H1, H1#2, H1#3, H1#4: MountingHole_2.5mm

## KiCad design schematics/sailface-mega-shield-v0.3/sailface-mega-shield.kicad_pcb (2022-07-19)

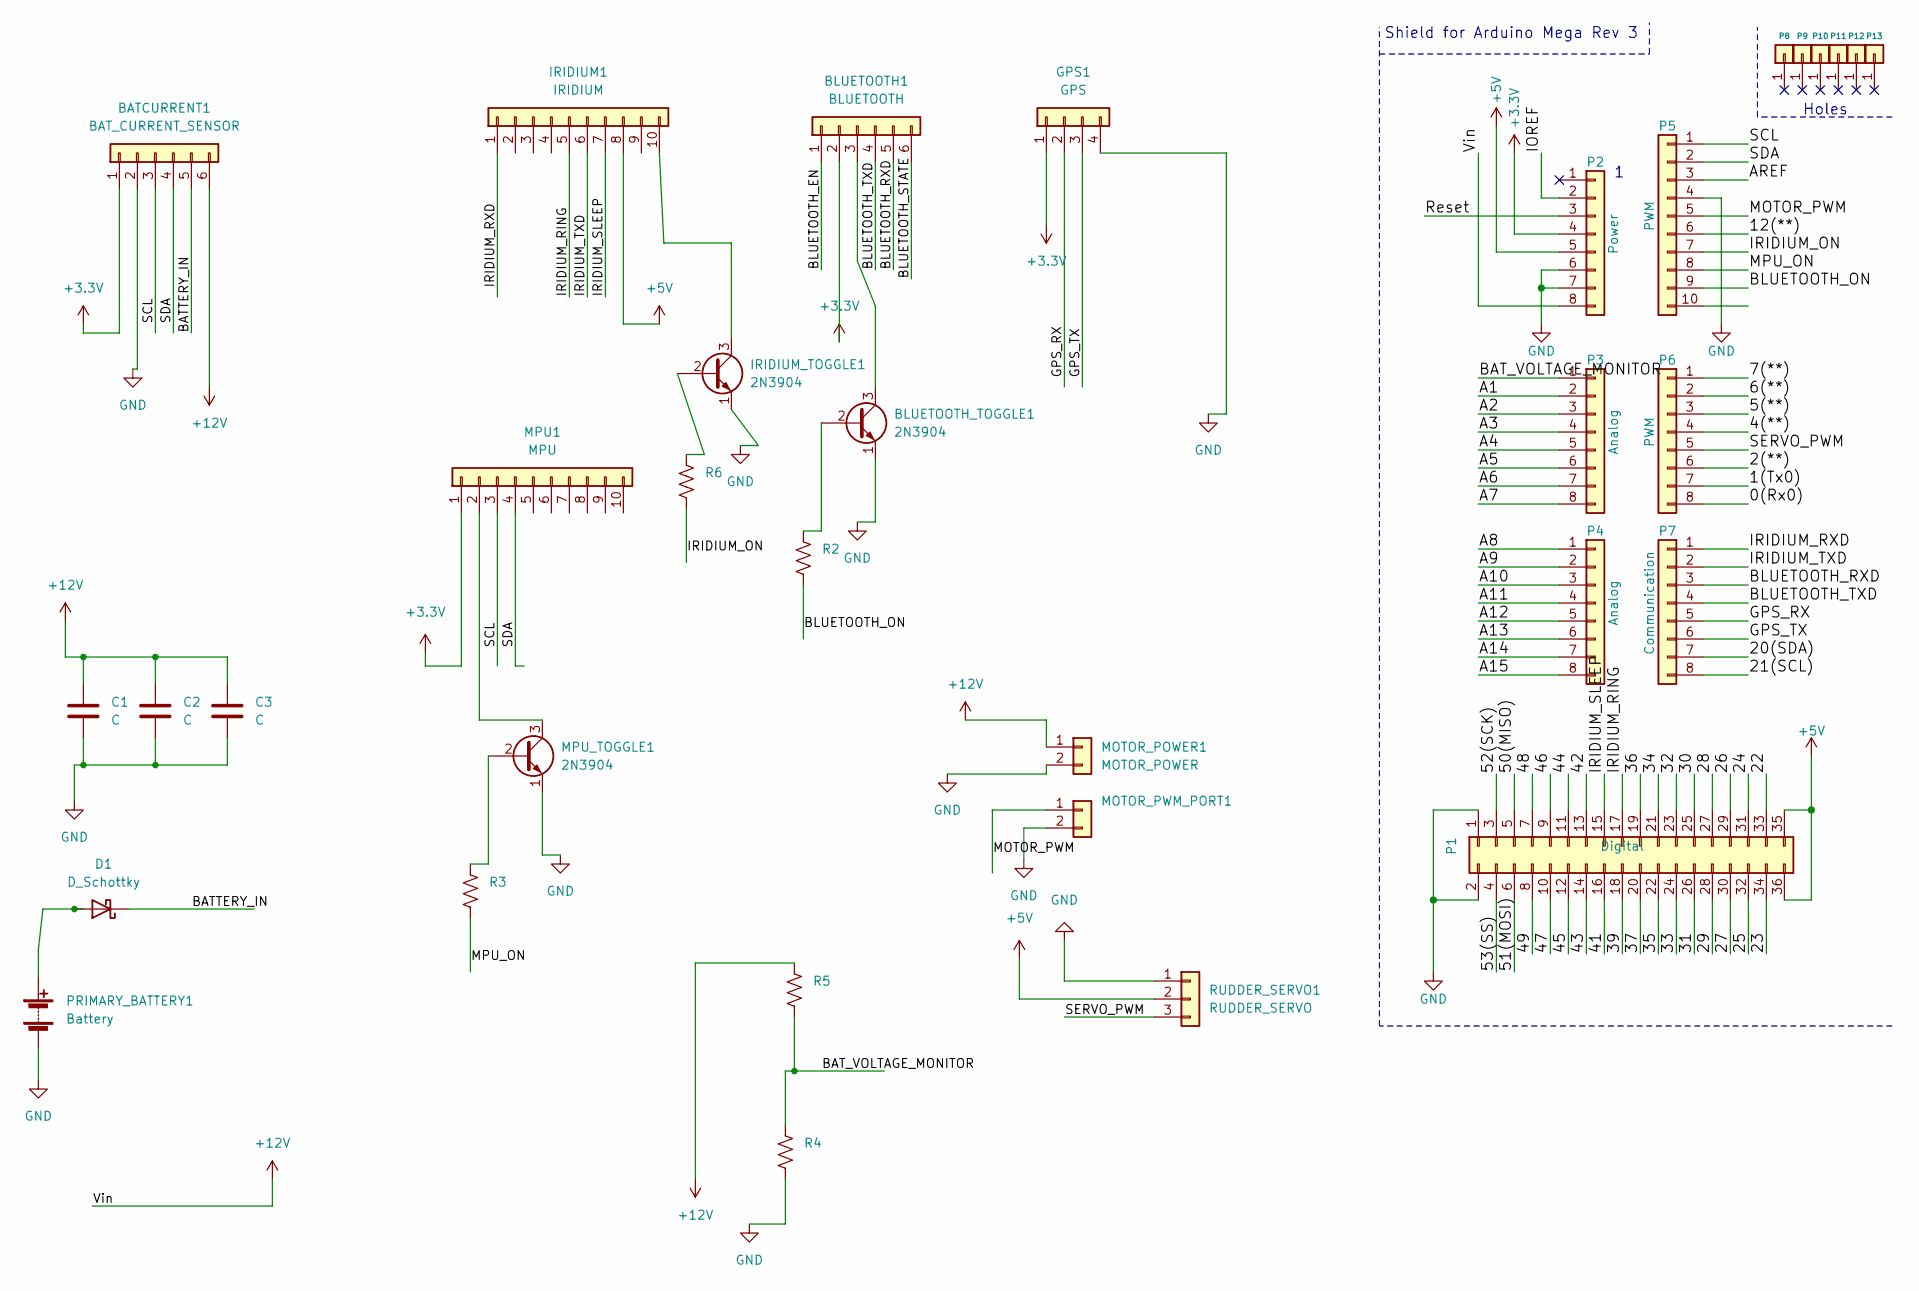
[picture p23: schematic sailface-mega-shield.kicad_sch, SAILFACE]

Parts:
BATCURRENT1: BAT_CURRENT_SENSOR; PinSocket_1x06_P2.54mm_Vertical
BLUETOOTH1: BLUETOOTH; PinSocket_1x06_P2.54mm_Vertical
BLUETOOTH_TOGGLE1: 2N3904; TO-92_Inline
C1, C2, C3: C; CP_Radial_D5.0mm_P2.00mm
D1: D_Schottky; D_5W_P5.08mm_Vertical_AnodeUp
GPS1: GPS; PinSocket_1x04_P2.54mm_Vertical
IRIDIUM1: IRIDIUM; PinSocket_1x10_P2.54mm_Vertical
IRIDIUM_TOGGLE1: 2N3904; TO-92_Inline
MOTOR_POWER1: MOTOR_POWER; PinSocket_1x02_P2.54mm_Vertical
MOTOR_PWM_PORT1: (no value)
MPU1: MPU; PinSocket_1x10_P2.54mm_Vertical
MPU_TOGGLE1: 2N3904; TO-92_Inline
P1: Digital; Socket_Strip_Arduino_2x18
P2: Power; Socket_Strip_Arduino_1x08
P3, P4: Analog; Socket_Strip_Arduino_1x08
P5: PWM; Socket_Strip_Arduino_1x10
P6: PWM; Socket_Strip_Arduino_1x08
P7: Communication; Socket_Strip_Arduino_1x08
P8, P9, P10, P11, P12, P13: CONN_01X01; Arduino_1pin
PRIMARY_BATTERY1: Battery; PinSocket_1x02_P2.54mm_Vertical
R2, R3, R4, R5, R6: (no value)
RUDDER_SERVO1: RUDDER_SERVO; PinSocket_1x03_P2.54mm_Vertical

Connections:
+3V3: BATCURRENT1.1, BLUETOOTH1.2, GPS1.1, MPU1.1, P2.4
+5V: IRIDIUM1.8, P1.35, P1.36, P2.5, RUDDER_SERVO1.2
+12V: BATCURRENT1.6, C1.1, C2.1, C3.1, MOTOR_POWER1.1, P2.8, R5.1; also elsewhere on the board
/0(Rx0): P6.8
/1(Tx0): P6.7
/2(**): P6.6
/4(**): P6.4
/5(**): P6.3
/6(**): P6.2
/7(**): P6.1
/12(**): P5.6
/20(SDA): P7.7
/21(SCL): P7.8
/22: P1.33
/23: P1.34
/24: P1.31
/25: P1.32
/26: P1.29
/27: P1.30
/28: P1.27
/29: P1.28
/30: P1.25
/31: P1.26
/32: P1.23
/33: P1.24
/34: P1.21
/35: P1.22
/36: P1.19
/37: P1.20
/39: P1.18
/41: P1.16
/42: P1.13
/43: P1.14
/44: P1.11
/45: P1.12
/46: P1.9
/47: P1.10
/48: P1.7
/49: P1.8
/50(MISO): P1.5
/51(MOSI): P1.6
/52(SCK): P1.3
/53(SS): P1.4
/A1: P3.2
/A2: P3.3
/A3: P3.4
/A4: P3.5
/A5: P3.6
/A6: P3.7
/A7: P3.8
/A8: P4.1
/A9: P4.2
/A10: P4.3
/A11: P4.4
/A12: P4.5
/A13: P4.6
/A14: P4.7
/A15: P4.8
/AREF: P5.3
/BATTERY_IN: BATCURRENT1.5, D1.1 (K)
/BAT_VOLTAGE_MONITOR: P3.1, R4.1, R5.2
/BLUETOOTH_EN: BLUETOOTH1.1
/BLUETOOTH_ON: P5.9, R2.2
/BLUETOOTH_RXD: BLUETOOTH1.5, P7.3
/BLUETOOTH_STATE: BLUETOOTH1.6
/BLUETOOTH_TXD: BLUETOOTH1.4, P7.4
/GPS_RX: GPS1.2, P7.5
/GPS_TX: GPS1.3, P7.6
/IOREF: P2.2
/IRIDIUM_ON: P5.7, R6.2
/IRIDIUM_RING: IRIDIUM1.5, P1.17
/IRIDIUM_RXD: IRIDIUM1.1, P7.1
/IRIDIUM_SLEEP: IRIDIUM1.7, P1.15
/IRIDIUM_TXD: IRIDIUM1.6, P7.2
/MOTOR_PWM: MOTOR_PWM_PORT1.1, P5.5; also elsewhere on the board
/MPU_ON: P5.8, R3.2
/Reset: P2.3
/SCL: BATCURRENT1.3, MPU1.3, P5.1
/SDA: BATCURRENT1.4, MPU1.4, P5.2
/SERVO_PWM: P6.5, RUDDER_SERVO1.3
GND: BATCURRENT1.2, BLUETOOTH_TOGGLE1.1 (E), C1.2, C2.2, C3.2, GPS1.4, IRIDIUM_TOGGLE1.1 (E), MOTOR_POWER1.2, MOTOR_PWM_PORT1.2, MPU_TOGGLE1.1 (E), P1.1, P1.2, P2.6, P2.7, P5.4, PRIMARY_BATTERY1.2 (-), R4.2, RUDDER_SERVO1.1; also elsewhere on the board
unnamed: BLUETOOTH1.3, BLUETOOTH_TOGGLE1.3 (C)
unnamed: BLUETOOTH_TOGGLE1.2 (B), R2.1
unnamed: D1.2 (A), PRIMARY_BATTERY1.1 (+)
unnamed: IRIDIUM1.10, IRIDIUM_TOGGLE1.3 (C)
unnamed: IRIDIUM_TOGGLE1.2 (B), R6.1
unnamed: MPU1.2, MPU_TOGGLE1.3 (C)
unnamed: MPU_TOGGLE1.2 (B), R3.1

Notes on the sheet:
Holes
Shield for Arduino Mega Rev 3

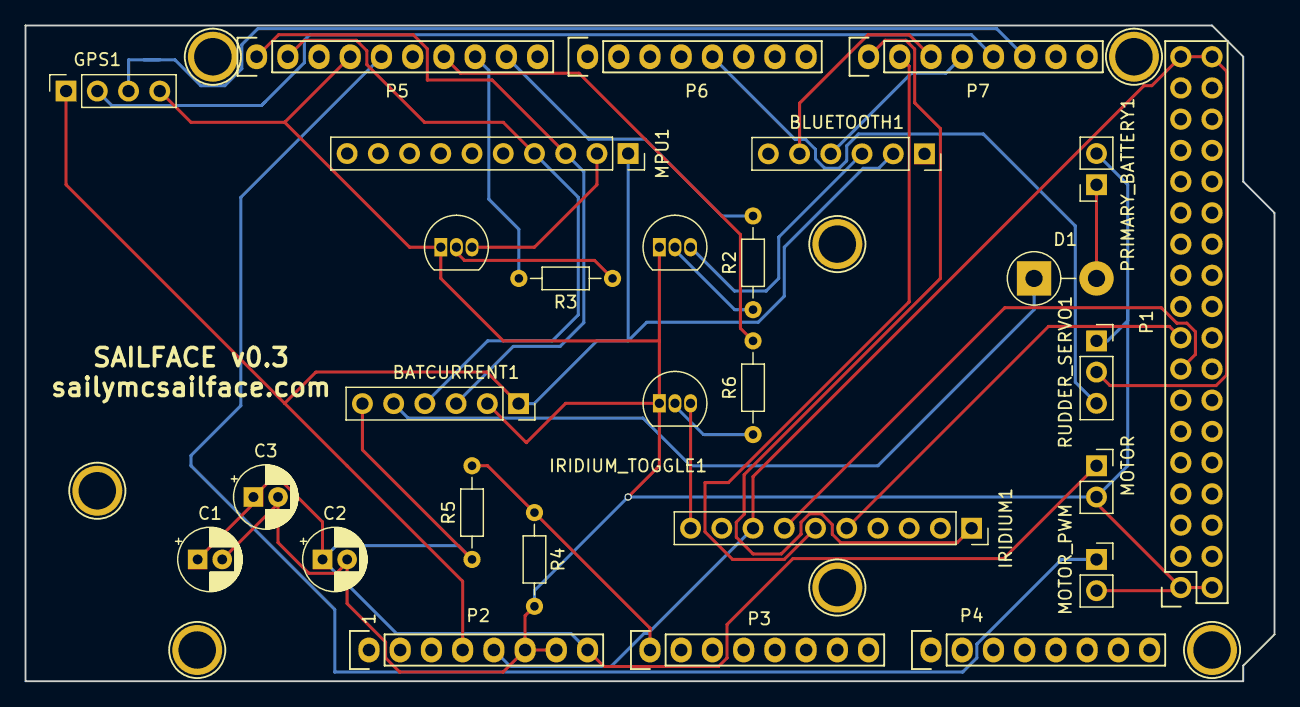
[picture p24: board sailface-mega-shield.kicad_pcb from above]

Board: 2 copper layers, 101.6 x 53.3 mm, 35 parts (0 on the bottom side), 28 nets.

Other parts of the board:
MOTOR: MOTOR_POWER; PinSocket_1x02_P2.54mm_Vertical
MOTOR_PWM: MOTOR_PWM_PORT; PinSocket_1x02_P2.54mm_Vertical
P11#2: CONN_01X01; Arduino_1pin

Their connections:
+12V: MOTOR.1; also elsewhere on the board
/MOTOR_PWM: MOTOR_PWM.1; also elsewhere on the board
GND: MOTOR.2, MOTOR_PWM.2; also elsewhere on the board

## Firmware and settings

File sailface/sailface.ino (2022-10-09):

#include "sailface.h"

#include "position.h"
#include "power.h"
#include "helm.h"
#include "propulsion.h"
#include "iridium.h"
#include "navigation.h"
#include "bluetooth_command.h"

PersistDataManager *persistedData;
PositionManager *position;
PowerManager *power;
HelmManager *helm;
PropManager *prop;
IridiumManager *iridium;
BluetoothCommand *bluetooth;
NavigationManager *navigation;


void setup(void) {
    // Uncomment for debug via Serial
    //Serial.begin(115200);

    persistedData = new PersistDataManager();
    position = new PositionManager();
    power = new PowerManager();
    helm = new HelmManager();
    prop = new PropManager();
    navigation = new NavigationManager();
    bluetooth = new BluetoothCommand();
    iridium = new IridiumManager();

    persistedData->initialize();
    position->initialize();
    power->initialize();
    helm->initialize();
    prop->initialize();
    navigation->initialize();
    bluetooth->initialize();
    iridium->initialize();
}

void loop(void) {
    sailfaceMainLoop(false);
}

bool ISBDCallback() {
    sailfaceMainLoop(true);

    // Do not cancel the Iridium transmit operation.
    return true;
}

/*
 * The main loop - Perform actions for each of the subsystems
 * The reason we are not using the Arduino built-in loop method is that the
 * IridiumSBD library blocks for 1-10 minutes as it attempts to transmit messages
 * to the satellite. During that time it repeatedly calls the ISBDCallback which we
 * define above. ISBDCallback will call sailfaceMainLoop so that operations can
 * continue as the Iridium modem attempts to transmit.
 * More information in the ISBD docs:
 * https://github.com/mikalhart/IridiumSBD/blob/master/extras/
    IridiumSBD%20Arduino%20Library%20Documentation.pdf
 */
void sailfaceMainLoop(bool iridiumBusy) {
    position->pollGPSForPosition();
    position->pollForMPU();

    navigation->pollForNavigationAdjustments();

    bluetooth->pollForBluetoothCommandMessages();

    if (!iridiumBusy) {
        iridium->pollForCommandMessages(false);
    }

    /*
    Todo: think about how we want to incorporate this later.
    if (globalStatus.radioControlActive) {
        pollAndProcessRadioCommands(&globalStatus);
    }
    */
}

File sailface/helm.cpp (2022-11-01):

/* Adjust the rudder to keep SailFace on a desired bearing.


A little PID theory from (https://playground.arduino.cc/Code/PIDLibrary/)

You tell the PID module what to measure (the "Input",) Where you want that
measurement to be (the "Setpoint",) and the variable to adjust that can make
that happen (the "Output".) The PID then adjusts the output trying to make
the input equal the setpoint.

For reference, in a car, the Input, Setpoint, and Output would be the speed,
desired speed, and gas pedal angle respectively.

In the case of SailFACE,
    Input - Current heading according to GPS module
    SetPoint - Desired Bearing (angle from current position to waypoint)
    and Output - Rudder position.

*/
#include "helm.h"
#include "sailface.h"

// TODO: If we wanna setup the RC receiver for close range driving.
// https://www.youtube.com/watch?v=u0Ft8SB3pkw
//

void HelmManager::initialize() {
    helmServo.attach(
        HELM_PWM_PIN,
        HELM_PWM_RANGE_MIN,
        HELM_PWM_RANGE_MAX
    );

    // LOAD PID parameters from persisted data.
    pidParams = persistedData->getPIDParams();

    enablePIDControl = false;
}

/* Update the PID parameters and reinitilize the PID controller to use them. */
void HelmManager::setPIDParams(PIDParams params) {
    pidParams = params;
    persistedData->storePIDParams(params);

    disablePID();
    setBearingAndEnablePID(desiredBearing);
}

PIDParams HelmManager::getPIDParams() {
    return pidParams;
}

/* Set the position of the rudder */
void HelmManager::setRudderPosition(int position) {
    /* Take a range between -10 and 10

    -10 is full to starboard
    10 is full to port

    */
    position = constrain(position, -10, 10);

    float stepSize = 0;
    if (position > 0) {
        stepSize = (RUDDER_SERVO_MAX_PORT - RUDDER_SERVO_CENTER) / 10.0;
    } else {
        stepSize = (RUDDER_SERVO_CENTER - RUDDER_SERVO_MAX_STARBOARD) / 10.0;
    }
    int servoAngle = RUDDER_SERVO_CENTER + int(stepSize * position);
    helmServo.write(servoAngle);
}

void HelmManager::setBearingAndEnablePID(int bearing) {

    // if PID control already enabled and if the new bearing is basically
    // same as the old bearing don't reinitialize the PID
    if (enablePIDControl == true) {
        if (abs(desiredBearing - bearing) < .5) {
            return;
        }
    }

    // clean up any old PID objects if needed
    disablePID();

    desiredBearing = bearing;
    enablePIDControl = true;

    difference = 0; // can we set this to a constant to start?
    //status->magneticCourse - status->magneticCourseVariation - status->desiredBearing;

    rudderPID = new PID(
        &difference,
        &pidRudderPositionOut,
        &setPoint,
        pidParams.Kp,
        pidParams.Ki,
        pidParams.Kd,
        DIRECT);

    rudderPID->SetMode(AUTOMATIC);
    rudderPID->SetOutputLimits(-10, 10);

}
void HelmManager::disablePID() {
    enablePIDControl = false;

    if (rudderPID) {
        delete rudderPID;
        rudderPID = NULL;
    }
}

void HelmManager::pollForRudderAdjustment(
    double curMagHeading,
    double curMagHeadingVariation,
    double desiredBearing
) {

    // only recompute rudder position every 2 seconds.
    unsigned long curTime = millis();
    if ((curTime - lastAdjustTime) < 2000) {
        return;
    }
    lastAdjustTime = curTime;


    // Either initialize PID controller or reinitialize if we have
    // changed our desired bearing.
    setBearingAndEnablePID(desiredBearing);


    // TODO(rmcl): This likely doesn't quite work. Revisit later.
    difference = curMagHeading - curMagHeadingVariation - desiredBearing;
    rudderPID->Compute();

    int newRudderPosition = int(pidRudderPositionOut);
    setRudderPosition(newRudderPosition);

    /*
    if (bluetooth->isBluetoothActive()) {
        HardwareSerial *bluetoothDebug = bluetooth->getBluetoothSerial();
        bluetoothDebug->println(
            String("INFO: NEW RUDDER POS") + String(newRudderPosition) + String("\n") + \
            String("CUR MAG:") + String(curMagHeading) + String(" MAG VAR:") + String(curMagHeadingVariation) + \
            String("Bearing to waypoint: ") + String(desiredBearing)
        );
    }
    */
}

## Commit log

2020-08-20 added solar power current INA219.
2020-09-07 added propulsion module for driving main prop.
2022-01-07 added logic for voltage divider.
2022-01-15 got distance and bearing to waypoint working.
2022-06-20 added megashield kicad files.
    [sailface-mega-shield.kicad_pcb, sailface-mega-shield.kicad_sch]
2022-07-11 added motor and motor holder model.
    [MotorAndHolder_v1.FCStd]
2022-07-11 vertical assembly and battery holder.
    [ServoSunFinderSF3218MG.FCStd, sailface_vertical_assembly_v1.FCStd]
2022-07-19 current state.
2022-07-19 circuit board.
    [sailface-mega-shield-B_Cu.gbl, sailface-mega-shield-B_Mask.gbs, sailface-mega-shield-B_Paste.gbp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]
2022-07-22 progress and renamed hardward to schematics.
    [sailface-mega-shield-B_Cu.gbl, sailface-mega-shield-B_Cu.gbr, sailface-mega-shield-B_Mask.gbr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]
2022-07-22 add 3d models.
    [ArduinoMega_STEP_AP203.STEP, Battery_VoltaicV70.FCStd, ElectronicAssembly.FCStd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]
2022-07-22 moving things around a bit.
    [MotorAndHolder_v1.FCStd, ServoHolder_v2.FCStd, ServoSunFinderSF3218MG.FCStd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]
2022-08-04 move bluetooth configure code out of sailforce device folder.
2022-08-18 tweak position to fix mpu.
    [position.cpp]
2022-08-18 save some 3d models.
    [ElectronicAssembly_v2.1.FCStd, ElectronicAssembly_v3.FCStd, MiddleConnector_v1.FCStd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]
2022-10-08 refactor position to use HMC5883 rather than accelerometer
2022-11-13 version 1.0.
    [Power.kicad_sch, microcontroller.kicad_sch, propulsion.kicad_sch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]
2022-11-13 add version to silkscreen.
    [sailboard-esp.kicad_pcb]
2022-11-23 v1.1 of sailboard.
    [Power.kicad_sch, microcontroller.kicad_sch, sailboard-esp.kicad_pcb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]
2022-11-26 version 1.1.
    [Power.kicad_sch, propulsion.kicad_sch, sailboard-esp.kicad_pcb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]
2022-12-07 add capacitor footprint.
    [Power.kicad_sch, propulsion.kicad_sch, sailboard-esp.kicad_pcb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]
2022-12-09 move to version 1.2.
    [Power.kicad_sch, microcontroller.kicad_sch, propulsion.kicad_sch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]
2022-12-11 additional tweaks to version 1.2.
    [sailboard-esp.kicad_pcb]
2022-12-11 more tweaks. Add mounting holes for rockblock.
    [sailboard-esp.kicad_pcb]
2022-12-14 added changelog and tweaks.
    [sailboard-esp.kicad_pcb, sailboard-esp.kicad_sch]
2022-12-30 rearrange pins to avoid ESP32 reserved / wonky pins.
    [Power.kicad_sch, microcontroller.kicad_sch, propulsion.kicad_sch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]
2022-12-30 tweaks to power.
